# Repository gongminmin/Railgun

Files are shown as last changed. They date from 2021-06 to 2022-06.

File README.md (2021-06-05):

# Railgun



A railgun is a type of mass driver. It contains a pair of rails to accelerate a conductor projectile to a high velocity. This project is a design of a toy level railgun. We'd like to make it easy to implement, so people can build it as a hobby project.

NOTE: Please turn on git LFS when cloning this project.

## Design

The principle of our design, and a detailed introduction of subsystems are in [Design](Doc/Design.md)

## Disclaimer

A railgun is operated by **LETHALLY** high voltage and current. If you don't have enough knowledge and experiences on high voltage electric, please keep extreme cautions on insulation.

## Directories

* Circuit folder is the electric design of the system. The files can be open by [KiCad](https://kicad-pcb.org/)
* Doc folder contains some documents

## License

Railgun is distributed under the terms of MIT License. See [LICENSE](LICENSE) for details.

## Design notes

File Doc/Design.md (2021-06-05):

# Design

The basic idea of railgun can be found at [wikipedia](https://en.wikipedia.org/wiki/Railgun). Here we implement a 3-stage coilgun. More stages can accelerate the projectile to a higher velocity.

Subsystems

## Operation Cycle

The propulsion system is running in cycles. Each cycle takes steps below.

1. The power starts charging capacitors in rail subsystem,
1. Push the manual trigger
1. The capacitor in rail subsystem is discharged
1. A high current go through the anode rail, projectile, and the cathode rail
1. The current generates a magnet field around the projectile
1. The electric field between rails push the magnet field to accelerate the projectile

## Subsystems

The system is composed of several subsystems.

### Power

The power subsystem converts 12V DC to 450V DC for charging capacitors.

See also [Power Subsystem](PowerSubsystem.md)

### Rail

When triggered, the capacitor discharge the energy to the rail in a very short time peroid.

See also [Rail Subsystem](RailSubsystem.md)

### Sensor

The sensor subsystem is optional. It tells the user the charging status of capacitors.

See also [Sensor Subsystem](SensorSubsystem.md)

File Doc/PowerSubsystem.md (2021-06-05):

# Power Subsystem

The power subsystem is a DC-DC converter, as the diagram below.

Power Subsystem

A main power source provides a high current 12V DC power. A ZVS drivers inverts it to low voltage AC. The output goes through a transformer to get high voltage AC. Then a full bridge rectifies it to high voltage DC.

## Power Source

The first module is a 12V DC power source. Put three 18650 batteries in serial makes it work. Note that this is the only power source in the system. Different subsystems share the same power.

## ZVS Driver

A ZVS driver is a circuit that can oscillate a large amount of DC power with very high efficiency. This design here is a well known one, invented by Vladimiro Mazzilli.

ZVS Circuit

It's also a finished board that can be found online. To make it oscillate, the output must be connected to a inductor, such as the primary coil of a transformer. Here we choose the inductance at 28uH, the output voltage is ~18V. The dual inductor ZVS driver doesn't need a center tapped primary coil. Make the circuit easier to connect.

ZVS Photo

## Transformer

The transformer has the turn configuration at 6:150. The 18V AC in the primary coil is transformed to 450V.

## Calculations

The resonant frequency of ZVS driver is detemined by its LC circuit.

`f = 1 / (2 * PI * sqrt(L * C))`

L is the primary coil of T1. It's measured as 28uH. And C here is 0.66uF. Put them into the equation, we have,

`f = 1 / (2 * PI * sqrt(0.000028 * 0.00000066)) = 37.0 kHz`

The impedance of the L is,

`X = 2 * PI * f * L = 2 * PI * 37000 * 0.000028 = 6.5 Ω`

## Future improvements

[TODO: Discussion about fast ZVS]

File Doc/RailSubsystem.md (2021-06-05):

# Rail Subsystem

## Capacitor and Rail

The capacitor is charged to 450V by power subsystem. A SCR controls the discharge. When it's triggered, the energy is transfered from capacitor to rail, generates a strong magnet field around the projectile.

Rail Circuit

The rail needs to be energized in a very short time. So we need a power source that provides high voltage and high current as a pulse. For doing this, high voltage capacitor is a much lighter and more efficient than put a bunch of batteries in serial for high voltage and in parallel for high current.

We choose SCRs here as a solid state switch. Compare to power MOSFETs, SCRs are good at handling high voltage and high current, with a lower frequency switching. These properties are exactly what we want. However, A SCR can't be turnned of by set a low leve signal to their gates. it keeps on until there is no potential difference between its anode and cathode. That means once triggered, the C1 discharges until it's empty. We have no control on discharge time.

**CAUSION**: Don't touch any metal part before capacitor finish discharging. The voltage and current are lethal.

## Calculations

The energy stores in one capacitor is:

`J = 0.5 * C * V * V = 0.5 * 0.00033 * 450 * 450 = 33.41 J`

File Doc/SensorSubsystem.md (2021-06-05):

# Sensor Subsystem

This is an optional subsystem. It doesn't provide the key functionality to the coilgun. Since capacitors may need seconds to finish charging, this subsystem helps user to know the status.

Sensor Subsystem

## Adapter

The adapter here is a linear divider. It takes an input voltage, divide it with a constant value, and send the result to voltage sensor. By using different values of resistors, we can adapt the same voltage sensor to different input voltages.

Sensor Adapter Circuit

## Voltage Sensor

The next part is a voltage sensor circuit. It takes a low voltage signal from adapter, compare it with reference voltages. During the charging, LEDs will be lit up one by one. If the capacitor is full, the 4th LED is on.

Voltage Sensor Circuit

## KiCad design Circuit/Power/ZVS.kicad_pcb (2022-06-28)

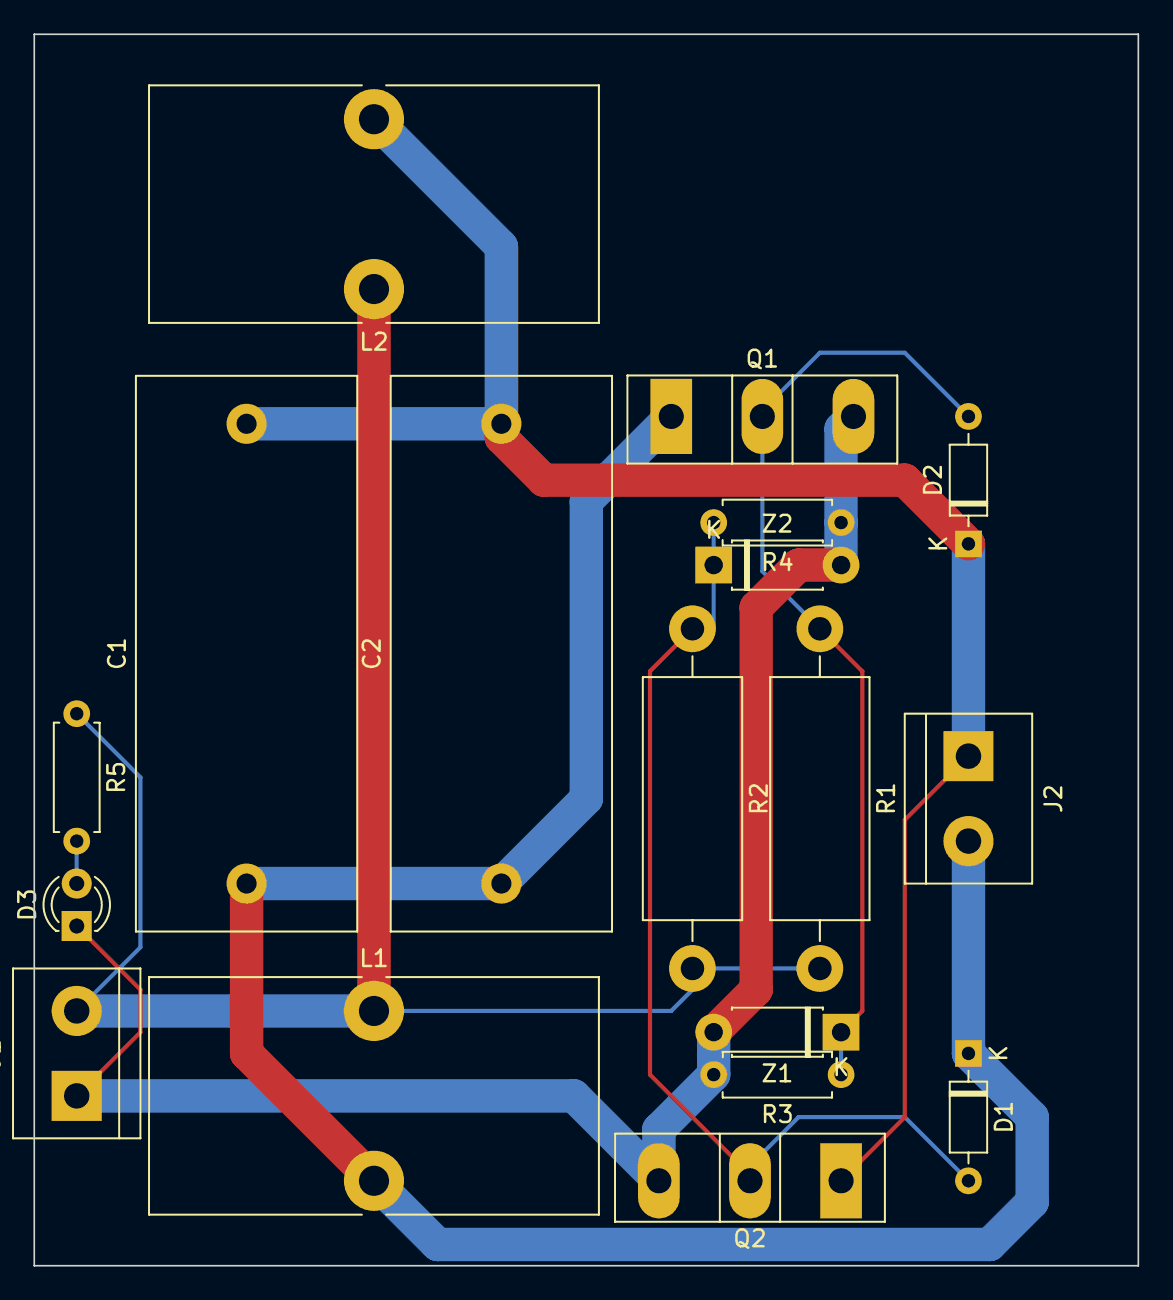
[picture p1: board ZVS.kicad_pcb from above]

Board: 2 copper layers, 66.0 x 73.7 mm, 18 parts (0 on the bottom side), 7 nets.

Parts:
C1, C2: MKP 0.33uF; C_Rect_L33.0mm_W13.0mm_P27.50mm_MKS4
D1, D2: FR107; D_DO-35_SOD27_P7.62mm_Horizontal
D3: LED; LED_D3.0mm_FlatTop
J1: 12V DC in; TerminalBlock_bornier-2_P5.08mm
J2: Output; TerminalBlock_bornier-2_P5.08mm
L1, L2: 100uH; L_Toroid_Vertical_L26.7mm_W14.0mm_P10.16mm_Pulse_D
Q1, Q2: IRFP250; TO-247-3_Vertical
R1, R2: 470 2W; R_Axial_DIN0614_L14.3mm_D5.7mm_P20.32mm_Horizontal
R3, R4: 10K; R_Axial_DIN0207_L6.3mm_D2.5mm_P7.62mm_Horizontal
R5: 2.2K; R_Axial_DIN0207_L6.3mm_D2.5mm_P7.62mm_Horizontal
Z1, Z2: 1N4742; D_DO-41_SOD81_P7.62mm_Horizontal

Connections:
/DCInput+: J1.2, L1.1, L2.1, R1.2, R2.2, R5.1
/DCInput-: D3.1, J1.1, Q1.3, Q2.3, R3.2, R4.1, Z1.2, Z2.2
/Output+: C1.1, C2.1, D1.1, J2.2, L1.2, Q1.1
/Output-: C1.2, C2.2, D2.1, J2.1, L2.2, Q2.1
unnamed: D1.2, Q2.2, R2.1, R4.2, Z2.1
unnamed: D2.2, Q1.2, R1.1, R3.1, Z1.1
unnamed: D3.2, R5.2

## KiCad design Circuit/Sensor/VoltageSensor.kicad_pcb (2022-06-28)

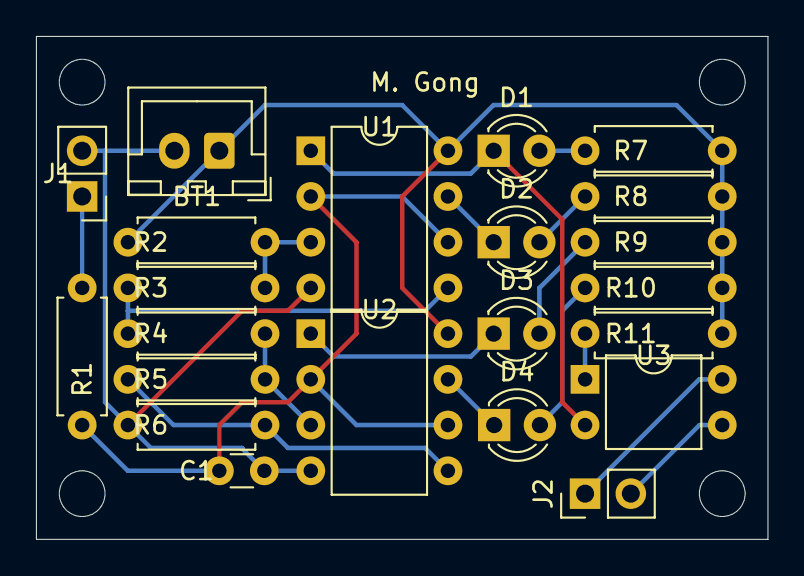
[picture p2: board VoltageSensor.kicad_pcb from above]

Board: 2 copper layers, 40.6 x 27.9 mm, 22 parts (0 on the bottom side), 19 nets.

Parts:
BT1: 12V Battery; JST_XH_B2B-XH-A_1x02_P2.50mm_Vertical
C1: 0.1uF; C_Disc_D3.0mm_W1.6mm_P2.50mm
D1, D2, D3, D4: LED; LED_D3.0mm_FlatTop
J1: From Capacitor Bank; PinHeader_1x02_P2.54mm_Vertical
J2: To Control; PinHeader_1x02_P2.54mm_Vertical
R1, R11: 1K; R_Axial_DIN0207_L6.3mm_D2.5mm_P7.62mm_Horizontal
R2: 20K; R_Axial_DIN0207_L6.3mm_D2.5mm_P7.62mm_Horizontal
R3, R4, R5, R6: 4.7K; R_Axial_DIN0207_L6.3mm_D2.5mm_P7.62mm_Horizontal
R7, R8, R9, R10: 2.2K; R_Axial_DIN0207_L6.3mm_D2.5mm_P7.62mm_Horizontal
U1, U2: LM393; DIP-8_W7.62mm
U3: PC817; DIP-4_W7.62mm

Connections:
+12V: BT1.1, R2.2, R7.1, R8.1, R9.1, R10.1, R11.1, U1.8 (V+), U2.8 (V+)
/ControlGND: J2.2, U3.3
/ControlSignal: J2.1, U3.4
/Sensor6V: J1.1, R1.2
GND: BT1.2, C1.2, J1.2, R6.1, U1.4 (V-), U2.4 (V-)
unnamed: C1.1, R1.1, U1.2 (-), U1.6 (_), U2.2 (-), U2.6 (_)
unnamed: D1.1 (K), U1.1, U3.2
unnamed: D1.2 (A), R7.2
unnamed: D2.1 (K), U1.7
unnamed: D2.2 (A), R8.2
unnamed: D3.1 (K), U2.1
unnamed: D3.2 (A), R9.2
unnamed: D4.1 (K), U2.7
unnamed: D4.2 (A), R10.2
unnamed: R2.1, R3.2, U1.3 (+)
unnamed: R3.1, R4.2, U1.5 (+)
unnamed: R4.1, R5.2, U2.3 (+)
unnamed: R5.1, R6.2, U2.5 (+)
unnamed: R11.2, U3.1

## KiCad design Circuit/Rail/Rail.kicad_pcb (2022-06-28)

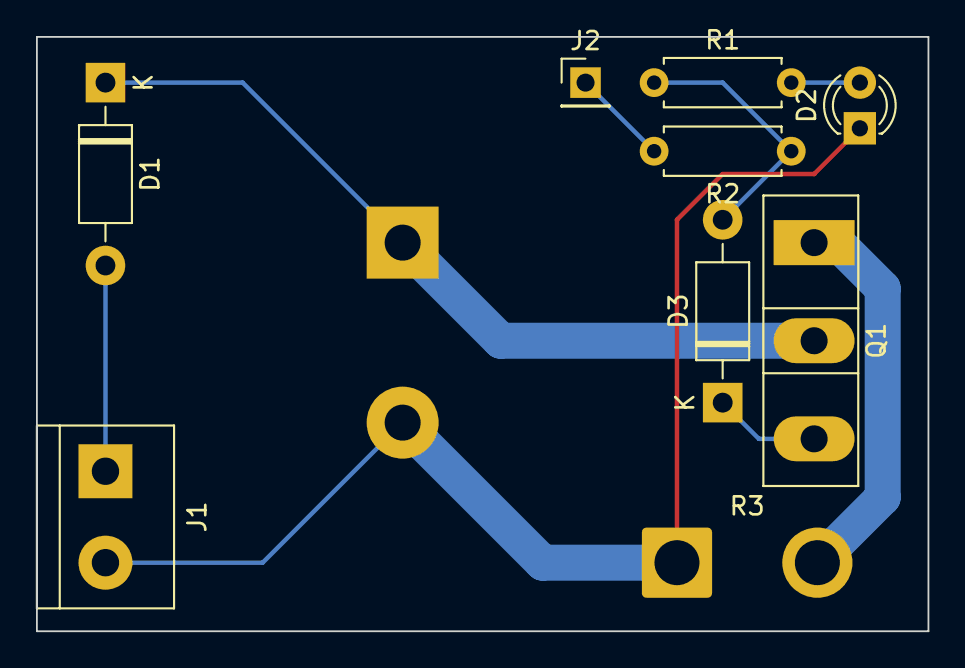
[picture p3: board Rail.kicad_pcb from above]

Board: 2 copper layers, 49.5 x 33.0 mm, 10 parts (1 on the bottom side), 8 nets.

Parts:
C1: 1000uF 450V; CP_Radial_D30.0mm_P10.00mm_SnapIn
D1, D3: 1N4007; D_DO-41_SOD81_P10.16mm_Horizontal
D2: LED; LED_D3.0mm_FlatTop
J1: Coil Power; TerminalBlock_bornier-2_P5.08mm
J2: Trigger; PinHeader_1x01_P2.54mm_Vertical
Q1: 70PT12DS; TO-247-3_Vertical
R1, R2: 2.2K; R_Axial_DIN0207_L6.3mm_D2.5mm_P7.62mm_Horizontal
R3: Rail; SolderWire-2sqmm_1x02_P7.8mm_D2mm_OD3.9mm

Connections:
/RailPower+: D1.2 (A), J1.1
/TriggerPower: J2.1, R2.2
GND: C1.2, D2.1 (K), J1.2, R3.1
unnamed: C1.1, D1.1 (K), Q1.2 (A)
unnamed: D2.2 (A), R1.2
unnamed: D3.1 (K), Q1.3 (G)
unnamed: D3.2 (A), R1.1, R2.1
unnamed: Q1.1 (K), R3.2

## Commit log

2021-06-05 Init commit
    [Power.sch, Rail.kicad_pcb, Rail.sch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]
2022-06-28 [Circuit] Update circuit files to KiCAD 6's
    [Power.kicad_sch, Power.sch, Rail.kicad_pcb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]
